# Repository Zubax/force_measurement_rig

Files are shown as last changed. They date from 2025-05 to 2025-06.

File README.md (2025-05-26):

# EPM force measurement rig (FMR)

This directory contains the sources of the holding force measurement rig (FMR) for the EPM:
the firmware for the device, the client PC software, and the CAD models.

## Build instructions

1. Prepare and assemble the mechanics according to the CAD models.

2. Build the firmware and prepare the electronics as explained in the firmware directory.
   Upload the firmware to the device.

3. Connect the assembled device to the PC. Make sure you can run the client software on your PC.

4. Perform the initial strain gauge calibration as explained in the documentation for the client software.

5. ???

6. PROFIT

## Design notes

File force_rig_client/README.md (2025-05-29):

# FluxGrip: demagnetization cycle optimization

This application is meant to be used to tune the demagnetization cycle of FluxGrip.

It consists of the following parts:

- _ForceMeasurementClient_: reads out measurements from _firmware_force_sensor_
- _StepperDriveClient_: controls the stepper driver (through _firmware_stepper_drive_) which moves the "arm" of the force measurement rig up/down
- _ConfigClient_: this clients allows to update the demagnetization cycle values on the FluxGrip (using Cyphal/CAN)

These 3 clients are used by _Optimizer_ to obtain the optimal demagnetization values.

## Installation

```shell
pip install -r requirements.txt
src/optimizer.py
```

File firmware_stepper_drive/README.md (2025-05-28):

# Microstep Driver Controller

This directory contains the firmware that runs on an ATmega328P connected to control a microstep driver (DM556).
To control the motor you will need to send commands using the serial interface:
- `forward`: drive forward
- `stop`: stop
- `back`: drive backwards

The serial port is configured at **38400-8N1**.

## Hardware configuration

| Microstep driver | Arduino |
|---|---|
| PUL+ | VDD |
| PUL- | D9/PB1 (PWM) |
| DIR+ | VDD |
| DIR+ | PB2 (GPIO) |
| ENA+ | **GND** |
| ENA- | **VDD** |

Note: The labeling on the microstep driver for ENA+/ENA- seems to be switched around.

## Development

Use `make` to build, `make dude` to upload to the board (using the built-in Arduino bootloader),
`make format` to invoke Clang-Tidy for autoformatting.

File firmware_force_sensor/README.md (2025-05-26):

# EPM FMR strain gauge digitizer firmware

This directory contains the sources of a simple firmware for the EPM force measurement rig (FMR) strain gauge digitizer
that runs on an ATmega328P connected to dedicated strain gauge ADCs.
The firmware samples the ADCs simultaneously at their maximum rate (about 10 Hz)
and reports each sample to the PC via serial port using a custom simple binary fixed-size-frame format
(refer to `main.c` for the details).
The serial port is configured at **38400-8N1**.
Each frame contains the following information:

- A magic value for start-of-frame and protocol version detection.
- A 64-bit sequence number that never overflows for data loss detection and digitizer restart detection.
- Raw ADC counts per ADC as `int32_t`.
- A few bytes of opaque calibration data in an application-specific format.

## Calibration data

The sensor calibration data is read from the non-volatile memory when the device is started.
The application can store arbitrary information there.
One obvious way to use it is to store a tuple of gain + offset per ADC channel.

The calibration data can be written by sending an appropriately formatted data packet;
please consult with the sources for the details.
Once the packet is received,
the non-volatile memory is rewritten and the following readings will be sent with the new data
(no restart needed).
The user can check whether the calibration data is replaced by waiting for the next packet.

## Hardware configuration

The MCU is expected to be installed on Arduino Nano or some compatible PCB.
The MCU should have the built-in Arduino bootloader, which is accessed via AVRDUDE.

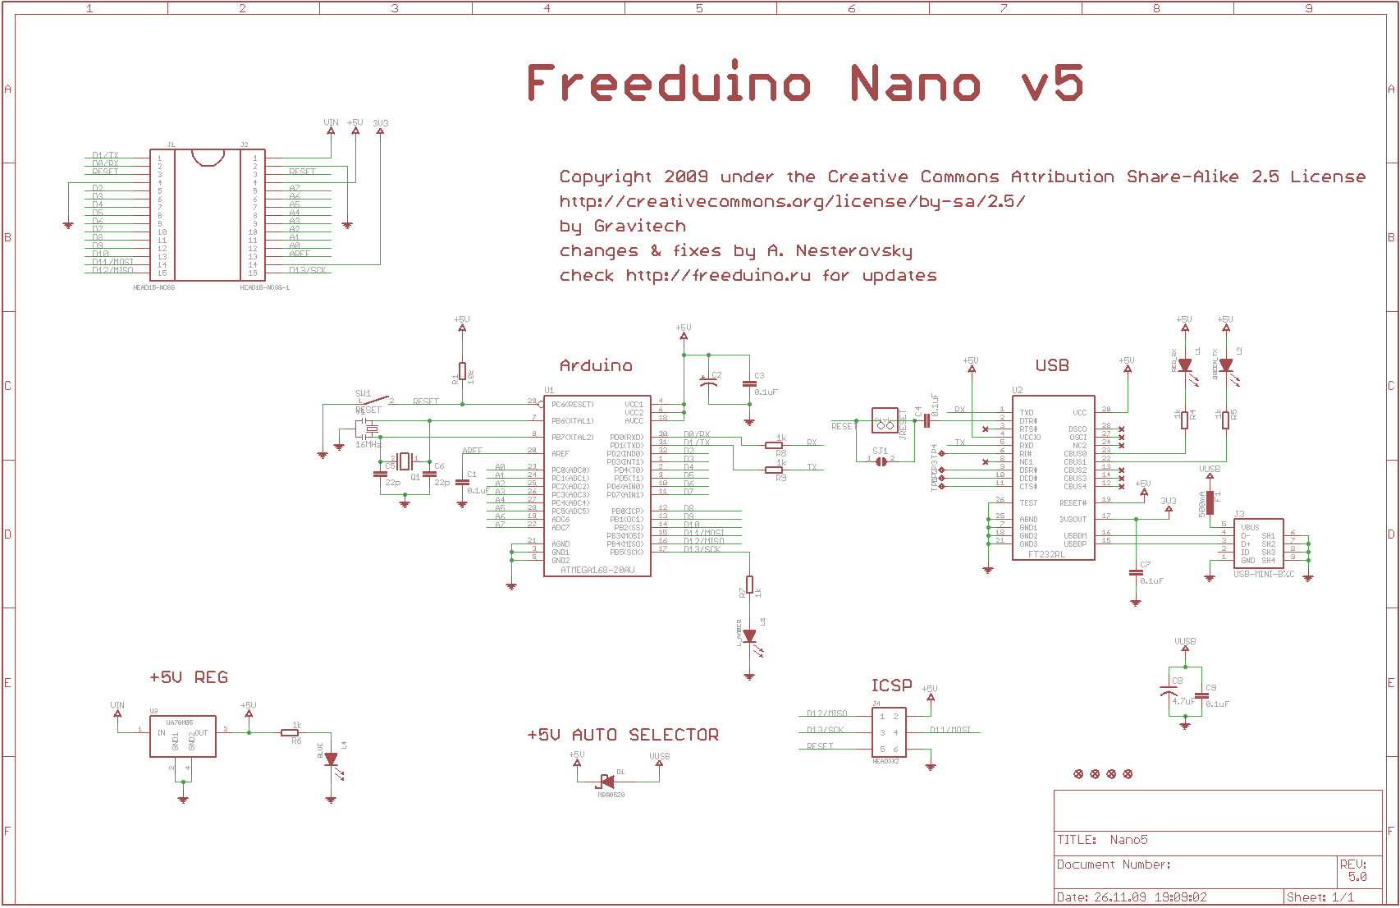
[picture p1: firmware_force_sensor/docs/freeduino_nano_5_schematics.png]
Arduino Nano schematics


The strain gauges are connected via HX711 -- dedicated 24-bit Wheatstone bridge ADCs with SPI-like interface.

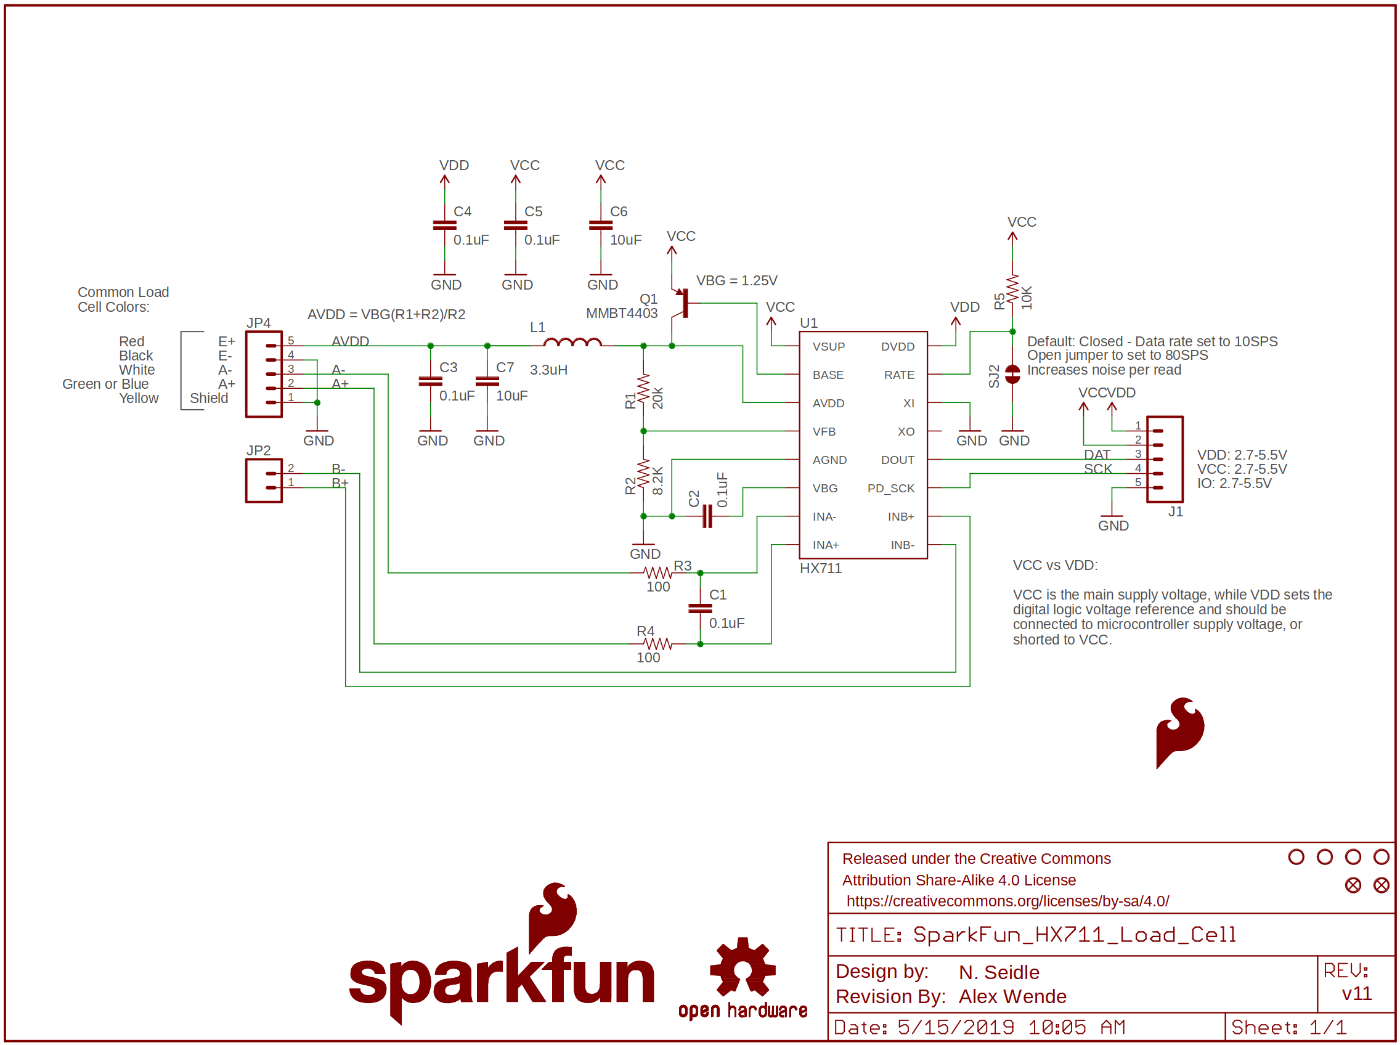
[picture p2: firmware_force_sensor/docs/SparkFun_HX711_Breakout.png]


The connections are as follows:

- PD2 -- shared clock signal SCK connected to all HX711 at once.
- PD3 -- DO of the load cell #0.
- PD4 -- DO of the load cell #1.
- more load cells may be added following this pattern.

Example of reading data from two HX711 using a shared clock signal:

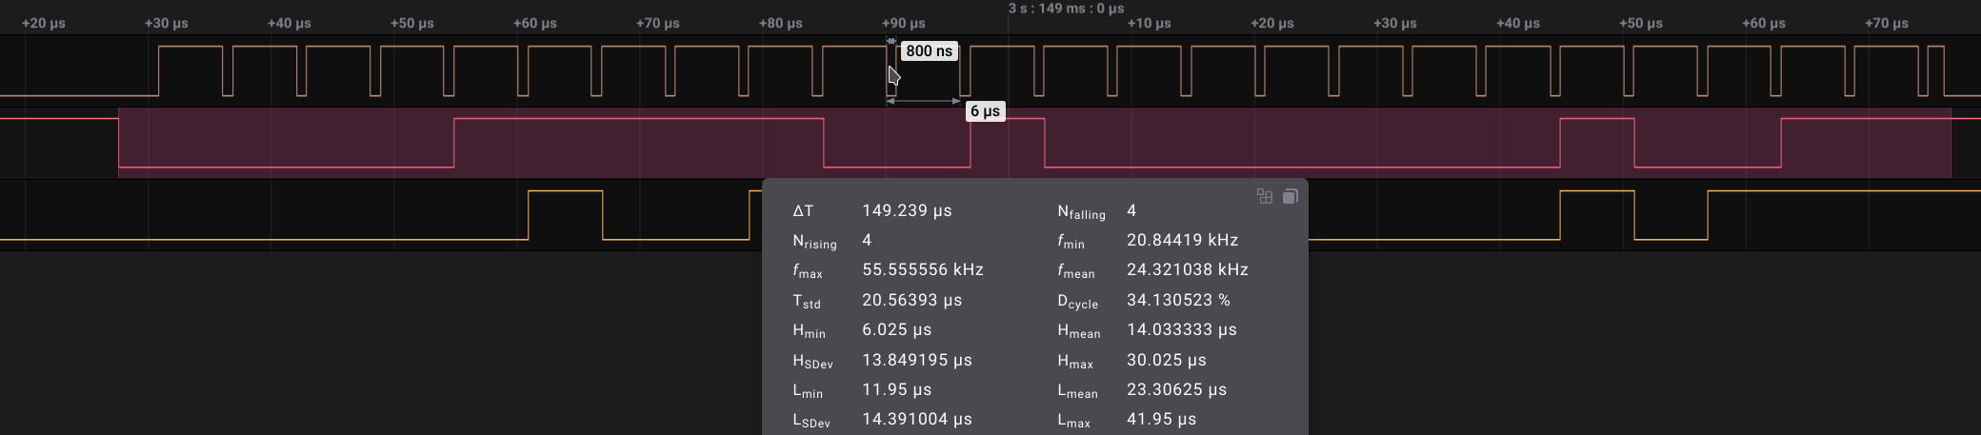
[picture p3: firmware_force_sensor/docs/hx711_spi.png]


## Development

Use `make` to build, `make dude` to upload to the board (using the built-in Arduino bootloader),
`make format` to invoke Clang-Tidy for autoformatting.

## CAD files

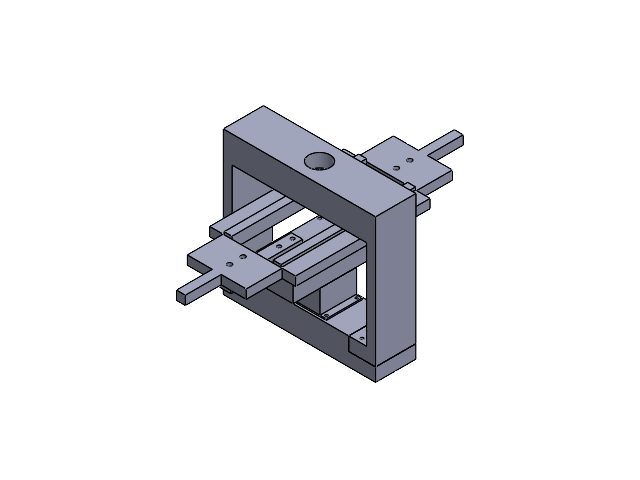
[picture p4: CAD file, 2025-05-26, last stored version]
force-rig.SLDASM
EPM-holder^new-force-rig
load-cell^new-force-rig x 2
load-holder^new-force-rig
EPM^new-force-rig
plate^new-force-rig
bottom^new-force-rig
top^new-force-rig

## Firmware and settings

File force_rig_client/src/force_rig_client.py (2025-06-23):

import asyncio
import time
from collections import deque
from matplotlib import pyplot

import click
import logging

import emoji
import serial
import sys
import numpy as np

from typing import Any, Callable, Coroutine
from shutil import get_terminal_size

from matplotlib.pyplot import savefig
from skopt import gp_minimize
from skopt.space import Integer

from client_utils import inform, coroutine

from force_rig import ForceRig
from force_sensor_interface import ForceSensorInterface
from fluxgrip_config import FluxGripConfig
# from src.bayesian_optimizer import search_space
from step_drive_control import StepDriveControl
from force_measurement_session import ForceMeasurementSession

from uavcan.primitive.array import Integer32_1

logging.basicConfig(level=logging.WARNING, format="%(asctime)s %(process)07d %(levelname)-3.3s %(name)s: %(message)s")
_logger = logging.getLogger(__name__)


@click.command(
    cls=click.Group,
    context_settings={
        "max_content_width": get_terminal_size()[0],
    },
)
@click.option("--verbose", "-v", count=True, help="Emit verbose log messages. Specify twice for extra verbosity.")
def cli(verbose: int) -> None:
    log_level = {
        0: logging.WARNING,
        1: logging.INFO,
        2: logging.DEBUG,
    }.get(verbose or 0, logging.DEBUG)
    logging.root.setLevel(log_level)


force_sensor_port_option = click.option(
    "--force-port",
    default="/dev/ttyUSB0",
    show_default=True,
    metavar="PORT_NAME",
    help="Force Sensor Serial port to use, or its URI",
    callback=lambda ctx, param, value: serial.serial_for_url(
        value,
        baudrate=ForceSensorInterface.BAUD,
        dsrdtr=None,  # On Arduino, DTR is used to reset the board, which we don't want.
        rtscts=None,
    ),
)


step_drive_port_option = click.option(
    "--drive-port",
    default="/dev/ttyUSB1",
    show_default=True,
    metavar="PORT_NAME",
    help="Step Drive Serial port to use, or its URI",
    callback=lambda ctx, param, value: serial.serial_for_url(
        value,
        baudrate=StepDriveControl.BAUD,
        dsrdtr=None,  # On Arduino, DTR is used to reset the board, which we don't want.
        rtscts=None,
    ),
)


@cli.command()
@force_sensor_port_option
@step_drive_port_option
@coroutine
async def execute(force_port: serial.Serial, drive_port: serial.Serial) -> None:
    """
    Execute a full force measurement cycle.
    Assumes that start is with arm at top position
    """
    test_values = [[-100,-90,-81,+73,+66,-59,-53,+48,+43,-39,-35,+31,+28,-25,-23,+21,+19,-17,-15,+14,-12,+11,-10,+9, 50, -45, 0, 0, 0, 0, 0, 0, 0, 0, 0, 0, 0, 0, 0, 0, 0, 0, 0, 0, 0, 0, 0, 0, 0, 0, 0],
                   [-100,-90,-81,+73,+66,-59,-53,+48,+43,-39,-35,+31,+28,-25,-23,+21,+19,-17,-15,+14,-12,+11,-10,+9, -50, 45, 0, 0, 0, 0, 0, 0, 0, 0, 0, 0, 0, 0, 0, 0, 0, 0, 0, 0, 0, 0, 0, 0, 0, 0, 0]]
    force_measurement_session = ForceMeasurementSession(force_port, drive_port)
    await force_measurement_session.setup()

    for value in test_values:
        average = await force_measurement_session.run_cycle(value)
        inform(f"\naverage f_peak: {average:.1f}")

    await force_measurement_session.cleanup()

@cli.command()
@force_sensor_port_option
@step_drive_port_option
def optimize(force_port: serial.Serial, drive_port: serial.Serial) -> None:
    """
    Optimize
    """
    # Good initial guess
    x0 = [
        8, 0, 24, -1, 7, -24, 11, -16, 24, -9, 17, -12, 10, -15, 22, -4, 9, -8, 3, -10, 7, -11, 2, 0, 5, -2
    ]
    y0 = 5.1
    force_measurement_session = ForceMeasurementSession(force_port, drive_port)

    loop = asyncio.new_event_loop()
    loop.run_until_complete(force_measurement_session.setup())

    N = len(x0)
    min_start, min_end = -50, -5
    max_start, max_end = 50, 5

    search_space = []
    for i in range(N):
        min_i = min_start + i * (min_end - min_start) / (N - 1)
        max_i = max_start + i * (max_end - max_start) / (N - 1)

        if i % 2 == 0:
            # even index: only positive values
            lower = max(0, min_i)
            upper = max(0, max_i)
        else:
            # odd index: only negative values
            lower = min(0, min_i)
            upper = min(0, max_i)

        # ensure integers
        search_space.append(Integer(int(lower), int(upper)))

    def optimize_target(params) -> float:
        FIXED_PRE_DEMAG_VALUES = [-100,-90,-81,+73,+66,-59,-53,+48,+43,-39,-35,+31,+28,-25,-23,+21,+19,-17,-15,+14,-12,+11,-10,+9,-8]
        result = loop.run_until_complete(force_measurement_session.run_cycle(params, FIXED_PRE_DEMAG_VALUES))
        return result


    res = gp_minimize(optimize_target, search_space, n_calls=300, random_state=42, x0=x0, y0=y0)
    inform(f"\n✅ Best force: {res.fun}")
    inform(f"\n🧲 Best demag values: {res.x}")

    loop.run_until_complete(force_measurement_session.cleanup())

def main() -> None:  # https://click.palletsprojects.com/en/8.1.x/exceptions/
    status: Any = 1
    # noinspection PyBroadException
    try:
        status = cli.main(standalone_mode=False)
    except SystemExit as ex:
        status = ex.code
    except (KeyboardInterrupt, click.Abort) as ex:
        status = 127
        _logger.info("Interrupted")
        _logger.debug("%s: %s", type(ex).__name__, ex, exc_info=True)
    except click.ClickException as ex:
        status = ex.exit_code
        try:
            inform("", fg="red", reset=False, nl=False)
            ex.show()
        finally:
            inform("", nl=False)
    except Exception as ex:  # pylint: disable=broad-except
        inform(f"Error (run with -v for more info): {type(ex).__name__}: {ex}", fg="red")
        _logger.info("Error: %s: %s", type(ex).__name__, ex, exc_info=True)
    except BaseException as ex:  # pylint: disable=broad-except
        inform(f"Internal error, please report: {ex}", fg="red")
        _logger.exception("%s: %s", type(ex).__name__, ex)
    _logger.debug("EXIT %r", status)
    sys.exit(status)


if __name__ == "__main__":
    main()

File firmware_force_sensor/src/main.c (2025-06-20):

// Copyright (C) 2023 Zubax Robotics

#include "platform.h"
#include "packet.h"

#define CALIBRATION_DATA_SIZE 40

struct reading
{
    uint64_t seq_num;
    uint64_t reserved_a;
    uint64_t reserved_b;
    int32_t  load_cell_raw[4];
    uint8_t  calibration_data[CALIBRATION_DATA_SIZE];
};
_Static_assert(sizeof(struct reading) == 80, "Invalid layout");  // NOLINT(readability-magic-numbers)

int main(void)
{
    platform_init();
    struct packet_parser parser  = {0};
    struct reading       reading = {0};
    platform_calibration_read(CALIBRATION_DATA_SIZE, reading.calibration_data);
    while (true)
    {
        // Read the next sample. The LED is off while waiting for the data.
        platform_led(false);
        platform_load_cell_read(reading.load_cell_raw);
        platform_led(true);
        // Send the reading.
        packet_send(sizeof(reading), &reading, platform_serial_write);
        // Prepare for the next iteration.
        platform_kick_watchdog();
        reading.seq_num++;

        // Process the pending incoming data. There may be many bytes accumulated in the buffer.
        while (true)
        {
            const int16_t rx = platform_serial_read();
            if (rx < 0)
            {
                break;
            }
            if (packet_parse(&parser, (uint8_t) rx))
            {
                platform_calibration_write(parser.payload_size, parser.payload);
                platform_calibration_read(CALIBRATION_DATA_SIZE, reading.calibration_data);
            }
        }
    }
    return 0;
}

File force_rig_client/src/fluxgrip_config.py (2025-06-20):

from __future__ import annotations

import re
import pycyphal
import logging
import asyncio
import collections.abc

from typing import Optional
from pathlib import Path
from typing import Iterator, Awaitable

from pycyphal.application import Node, make_transport
from pycyphal.application.node_tracker import NodeTracker
from pycyphal.application.register import ValueProxy, ValueProxyWithFlags, Natural16, Natural32
from pycyphal.transport import Transport
from pycyphal.presentation import Publisher, Subscriber

# DSDL imports
from uavcan.node import GetInfo_1
from uavcan.node import ExecuteCommand_1
from uavcan.primitive.array import Integer32_1
from uavcan.primitive.scalar import Integer8_1
from uavcan.register import Access_1, List_1, Name_1
from zubax.fluxgrip import Feedback_0

_logger = logging.getLogger(__name__)


class RegisterProxy(collections.abc.Mapping[str, pycyphal.application.register.ValueProxyWithFlags]):
    _VALID_PAT = re.compile(r"^[a-z_]+(\.\w+)+[<=>]?$")

    def __init__(self, local_node: pycyphal.application.Node, remote_node_id: int):
        self._cache: dict[str, ValueProxyWithFlags] = {}
        self._acc = local_node.make_client(Access_1, remote_node_id)
        self._list = local_node.make_client(List_1, remote_node_id)

    @property
    def remote_node_id(self) -> int:
        return int(self._acc.output_transport_session.destination_node_id)

    @staticmethod
    async def new(local_node: pycyphal.application.Node, remote_node_id: int) -> RegisterProxy:
        rp = RegisterProxy(local_node, remote_node_id)
        await rp.reload()
        return rp

    async def reload(self) -> None:
        """
        Invalidate the local cache and fetch all registers from the remote node anew.
        This is basically equivalent to creating a new instance.
        """
        _logger.debug("{!r}: Reloading", self)
        names: set[str] = set()
        for idx in range(2**16):
            req = List_1.Request(idx)
            resp = await self._list(req)
            if not resp:
                raise pycyphal.application.NetworkTimeoutError(f"Register list has timed out: {req}")
            assert isinstance(resp, List_1.Response)
            if name := resp.name.name.tobytes().decode():
                assert self._VALID_PAT.match(name), f"Invalid register name: {name!r}"
                names.add(name)
            else:
                break
        self._cache.clear()
        for n in names:
            await self.read_through(n)
        _logger.debug("Fetched registers:")
        for key, value in self._cache.items():
            _logger.debug(f"{key} -> {repr(value)}")
        assert names == set(self._cache.keys())

    async def read_through(self, name: str) -> ValueProxyWithFlags:
        """
        Fetch the register from the remote node and update the local cache.
        Returns empty if no such register, in which case the cache is not altered.
        Raises pycyphal.application.NetworkTimeoutError on timeout.
        """
        return await self.write_through(name, pycyphal.application.register.Value())

    async def write_through(self, name: str, value: pycyphal.application.register.RelaxedValue) -> ValueProxyWithFlags:
        """
        Write the specified register on the remote node, update the cache with the response.
        Returns empty if no such register, in which case the cache is not altered.
        Raises pycyphal.application.NetworkTimeoutError on timeout.
        If the value is empty, this is equivalent to a read operation.
        """
        if name in self._cache:
            _logger.debug("{!r}: {!r} was found in cache!", self, name)
            v_with_flags = self._cache[name]  # copy is necessary to use correct type stored in value!
            v_with_flags.assign(value)  # update the value
            v = v_with_flags.value
        else:
            _logger.debug("{!r}: {!r} was not found in cache!", self, name)
            v = pycyphal.application.register.ValueProxy(value).value
            _logger.debug("{!r}: type of value: {!r}", self, type(v))
        req = Access_1.Request(name=Name_1(name), value=v)
        resp = await self._acc(req)
        if not resp:
            await asyncio.sleep(10)
            resp = await self._acc(req)
            if not resp:
                raise pycyphal.application.NetworkTimeoutError(f"Register access has timed out: {req}")
        assert isinstance(resp, Access_1.Response)
        res = ValueProxyWithFlags(resp.value, resp.mutable, resp.persistent)
        if not res.value.empty:
            self._cache[name] = res
            _logger.debug("{!r}: {!r} <- {!r}", self, name, res)
        return res

    def __getitem__(self, k: str) -> ValueProxyWithFlags:
        """Obtain item from the cache (does not access the network). The value may be obsolete."""
        return self._cache[k]

    def __len__(self) -> int:
        return len(self._cache)

    def __iter__(self) -> Iterator[str]:
        """Iterate the cached values, which may be obsolete (does not access the network)."""
        return iter(self._cache)

    def __repr__(self) -> str:
        return str(
            pycyphal.util.repr_attributes(
                self, remote_node_id=self._acc.output_transport_session.destination_node_id, size=len(self._cache)
            )
        )

    def __str__(self) -> str:
        if len(self) == 0:
            return ""
        max_name_len = max(map(len, self.keys()))
        return "\n".join(
            "\t".join(
                [
                    k.ljust(max_name_len),
                    ("immutab", "mutable")[v.mutable],
                    ("volatil", "persist")[v.persistent],
                    str(pycyphal.dsdl.to_builtin(v.value)),
                ]
            )
            for k, v in sorted(self.items())
        )


DEFAULT_CONTROLLER_NODE_ID = 1
DEFAULT_TARGET_NODE_ID = 125
EXPECTED_COMMAND_TOPIC_ID = 1000
EXPECTED_FEEDBACK_TOPIC_ID = 1001
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

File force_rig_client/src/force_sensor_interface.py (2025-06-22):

from __future__ import annotations

import asyncio
import dataclasses
import struct
import serial
import logging
import numpy as np

from serial_interface import IOManager, Packet
from numpy.typing import NDArray
from typing import Optional, TypeVar, Generic

logging.basicConfig(level=logging.DEBUG, format="%(asctime)s %(process)07d %(levelname)-3.3s %(name)s: %(message)s")
_logger = logging.getLogger(__name__)

T = TypeVar("T")


class MovingAverage(Generic[T]):
    """
    >>> ma = MovingAverage(3, 0)
    >>> ma(1)  # doctest: +ELLIPSIS
    0.333...
    >>> ma(2)  # doctest: +ELLIPSIS
    1.0
    >>> ma(3)  # doctest: +ELLIPSIS
    2.0

    >>> maa = MovingAverage(3, np.array([1, 2, 3]))
    >>> maa(np.array([2, 2, 2]))  # doctest: +ELLIPSIS, +NORMALIZE_WHITESPACE
    array([1.333..., 2..., 2.666...])
    >>> maa(np.array([2, 2, 2]))  # doctest: +ELLIPSIS, +NORMALIZE_WHITESPACE
    array([1.666..., 2..., 2.333...])
    >>> maa(np.array([2, 2, 2]))  # doctest: +ELLIPSIS, +NORMALIZE_WHITESPACE
    array([2..., 2..., 2...])
    """

    def __init__(self, depth: int, initial: T) -> None:
        self._values = [initial] * depth
        self._sum = sum(self._values)  # type: ignore
        self._index = 0

    def __call__(self, value: T) -> T:
        self._sum -= self._values[self._index]  # type: ignore
        self._values[self._index] = value
        self._sum += value  # type: ignore
        self._index = (self._index + 1) % len(self._values)
        return self._sum * (1 / len(self._values))  # type: ignore


@dataclasses.dataclass(frozen=True)
class ForceSensorReading:
    """
    A single reading reported by the digitizer.
    """

    seq_num: int
    adc_readings: NDArray[np.int32]
    calibration: NDArray[np.float64]

    CHANNEL_COUNT = 2


class ForceSensorInterface(IOManager):
    """
    Reads the data from the serial port and parses it into readings.
    Also allows sending commands to the digitizer.

    >>> import serial
    >>> import time
    >>> port = serial.serial_for_url("loop://")
    >>> valid_packet = bytes.fromhex(
    ...     "B44CECF250000000"
    ...     "020000000000000000000000000000000000000000000000"
    ...     "00998F0F00BC64040000000000000000"
    ...     "FFFFFFFFFFFFFFFFFFFFFFFFFFFFFFFFFFFFFFFFFFFFFFFFFFFFFFFFFFFFFFFFFFFFFFFFFFFFFFFF"
    ...     "473D")
    >>> _ = port.write(valid_packet)
    >>> async def test():
    ...     reader = ForceSensorInterface(port)
    ...     reading = await reader.fetch(timeout=1)
    ...     assert reading is not None
    ...     assert reading.seq_num == 2
    ...     assert (reading.adc_readings == [261069056, 73710592, 0, 0]).all()
    ...     assert reading.calibration.shape == (2, 4)
    ...     reading = await reader.fetch(timeout=1)
    ...     assert reading is None
    ...     reader.close()
    >>> asyncio.run(test())
    """

    _STRUCT_READING = struct.Struct(r"< Q 8x 8x 16s 40s")

    def __init__(self, port: serial.Serial, fir_order: int = 2) -> None:
        super().__init__(port)
        self._port: serial.Serial = port
        self._fir_order: int = fir_order
        self._zero_bias: Optional[NDArray[np.float64]] = None
        self._lpf: Optional[MovingAverage[np.float64]] = None
        self._f_peak: np.float64 = np.float64(0)

    async def read(self, deadline: float) -> ForceSensorReading | None:
        """
        Waits for up to the specified deadline for a new reading to arrive.
        Returns the new reading, or None if the deadline has expired.
        """
        while True:
            if pkt := await self._once():
                seq_num, adc_readings, calibration = self._STRUCT_READING.unpack_from(pkt.payload)
                rd = ForceSensorReading(
                    seq_num=seq_num,
                    adc_readings=np.frombuffer(
                        adc_readings,
                        dtype=np.int32,
                        count=ForceSensorReading.CHANNEL_COUNT,
                    ),
                    calibration=np.frombuffer(
                        calibration,
                        dtype=np.float32,
                        count=ForceSensorReading.CHANNEL_COUNT * 2,
                    )
                    .reshape((2, ForceSensorReading.CHANNEL_COUNT))
                    .astype(np.float64),
                )
                _logger.debug("%s: Received reading %s", self, rd)
                return rd
            if deadline < asyncio.get_event_loop().time():
                return None
            await asyncio.sleep(1e-3)  # This is silly but works for the MVP.

    async def write_calibration(self, cal: NDArray[np.float64]) -> bool:
        """
        Writes the calibration data to the digitizer and waits for confirmation.
        Returns True if the calibration was accepted, False otherwise (in which case retrying may help).
        """
        payload = cal.astype(np.float32).tobytes()
        buf = Packet(memoryview(payload)).compile()
        _logger.debug("%s: Sending calibration packet: %s", self, buf.hex())
        await asyncio.get_event_loop().run_in_executor(self._executor, self._port.write, buf)
        await asyncio.sleep(1.0)  # Wait for the new data to be processed.
        await self.flush()
        rd = await self.read(asyncio.get_event_loop().time() + 10)
        if rd is None:
            _logger.debug("%s: Calibration confirmation timed out", self)
            return False
        _logger.info(
            "%s: Received calibration confirmation. Sent calibration:\n%s\nReceived calibration:\n%s",
            self,
            cal,
            rd.calibration,
        )
        return np.allclose(rd.calibration, cal, atol=1e-3, rtol=1e-3, equal_nan=True)

    async def do_bias_calibration(self, uncalibrated_forces: NDArray[np.float64], n_samples: int) -> NDArray[np.float64]:
        agg = np.zeros_like(uncalibrated_forces)
        log_interval = max(n_samples // 10, 1) # Log progress at 10% intervals

        for i in range(n_samples):
            agg += self.compute_forces(await self.fetch())
            if (i+1) % log_interval == 0 or i == n_samples - 1:
                _logger.debug("Calibrating bias... %d/%d samples collected", i + 1, n_samples)

        return agg / n_samples

    async def fetch(self, flush=False) -> ForceSensorReading:
        if flush:
            await self.flush()
        rd = await self.read(deadline=asyncio.get_running_loop().time() + 10.0)
        if rd is None:
            raise RuntimeError("Timed out while waiting for data")
        return rd

    async def get_instant_forces(self, calibrate=False) -> NDArray[np.float64]:
        if calibrate:
            rd = await self.fetch(flush=True)
            forces = self.compute_forces(rd)
            self._zero_bias = await self.do_bias_calibration(forces, 50)
            _logger.debug(f"Zero bias: {self._zero_bias} N")
        rd = await self.fetch(flush=True)
        forces = self.compute_forces(rd) - self._zero_bias
        return forces
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

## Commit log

2025-05-27 Add firmware stepper drive
2025-05-28 Add stepper driver client code
2025-05-29 Update stepper driver to be able to process commands
2025-06-15 Cleanup, renaming
    [force-rig.SLDASM]
2025-06-20 Force sensor API
